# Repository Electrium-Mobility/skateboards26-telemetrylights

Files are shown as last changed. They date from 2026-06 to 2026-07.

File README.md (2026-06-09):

# Design

This is a mixed telemetry + lights board. We will use sensors (accelerometer) to gather information, a STM to process the info, and lights/display to display the result. Depending on the acceleration of the skateboard, the lights change to a different color. Data will also be displayed on a LCD/OLED screen.

Items displayed are:

* Acceleration
* Current/voltage draw of our board
* Precharge current sense
  * For the last two points, assume a separate power distribution board will be connected, and will be providing those signals through connectors.

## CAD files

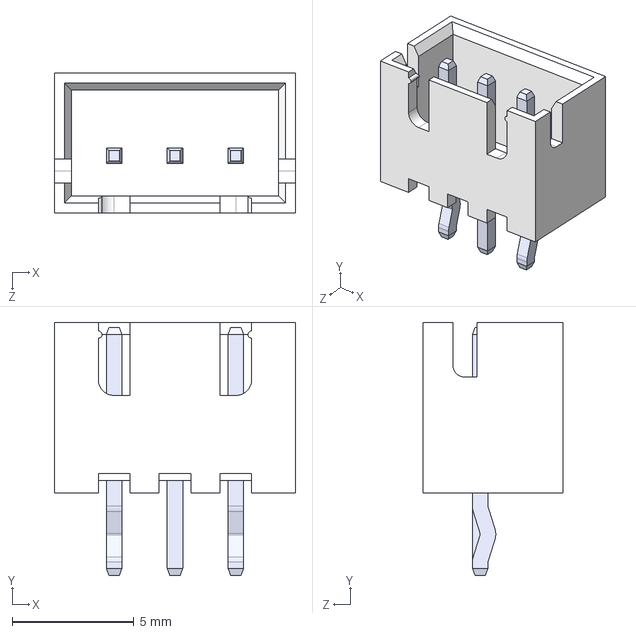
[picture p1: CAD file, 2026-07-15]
skateboard-3d-models/B3B-XH-A.STEP
9.90 x 10.4 x 5.75 mm

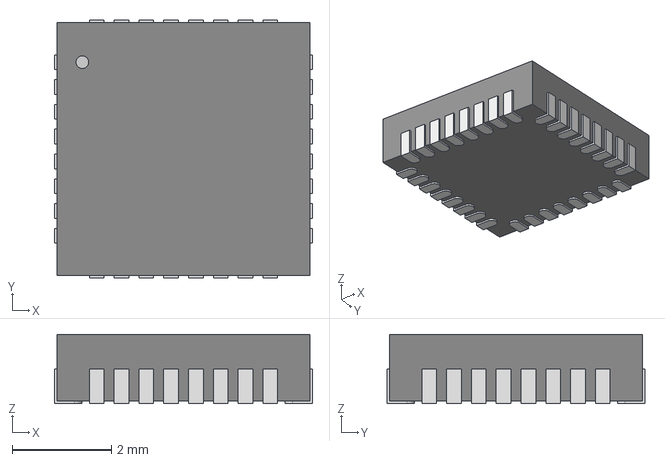
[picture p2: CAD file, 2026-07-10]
skateboard-3d-models/UFQFPN-32.step
5.20 x 5.20 x 1.40 mm

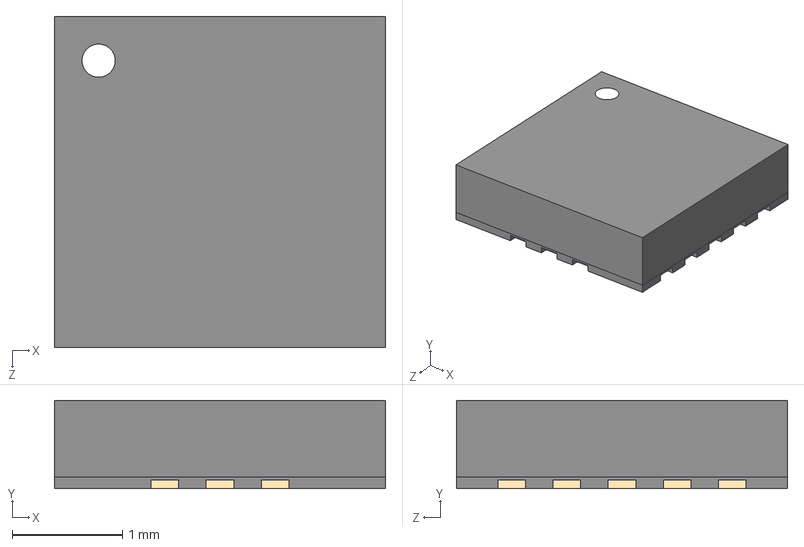
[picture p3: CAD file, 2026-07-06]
skateboard-3d-models/IAM-20381HT.step
3.00 x 0.8 x 3.00 mm

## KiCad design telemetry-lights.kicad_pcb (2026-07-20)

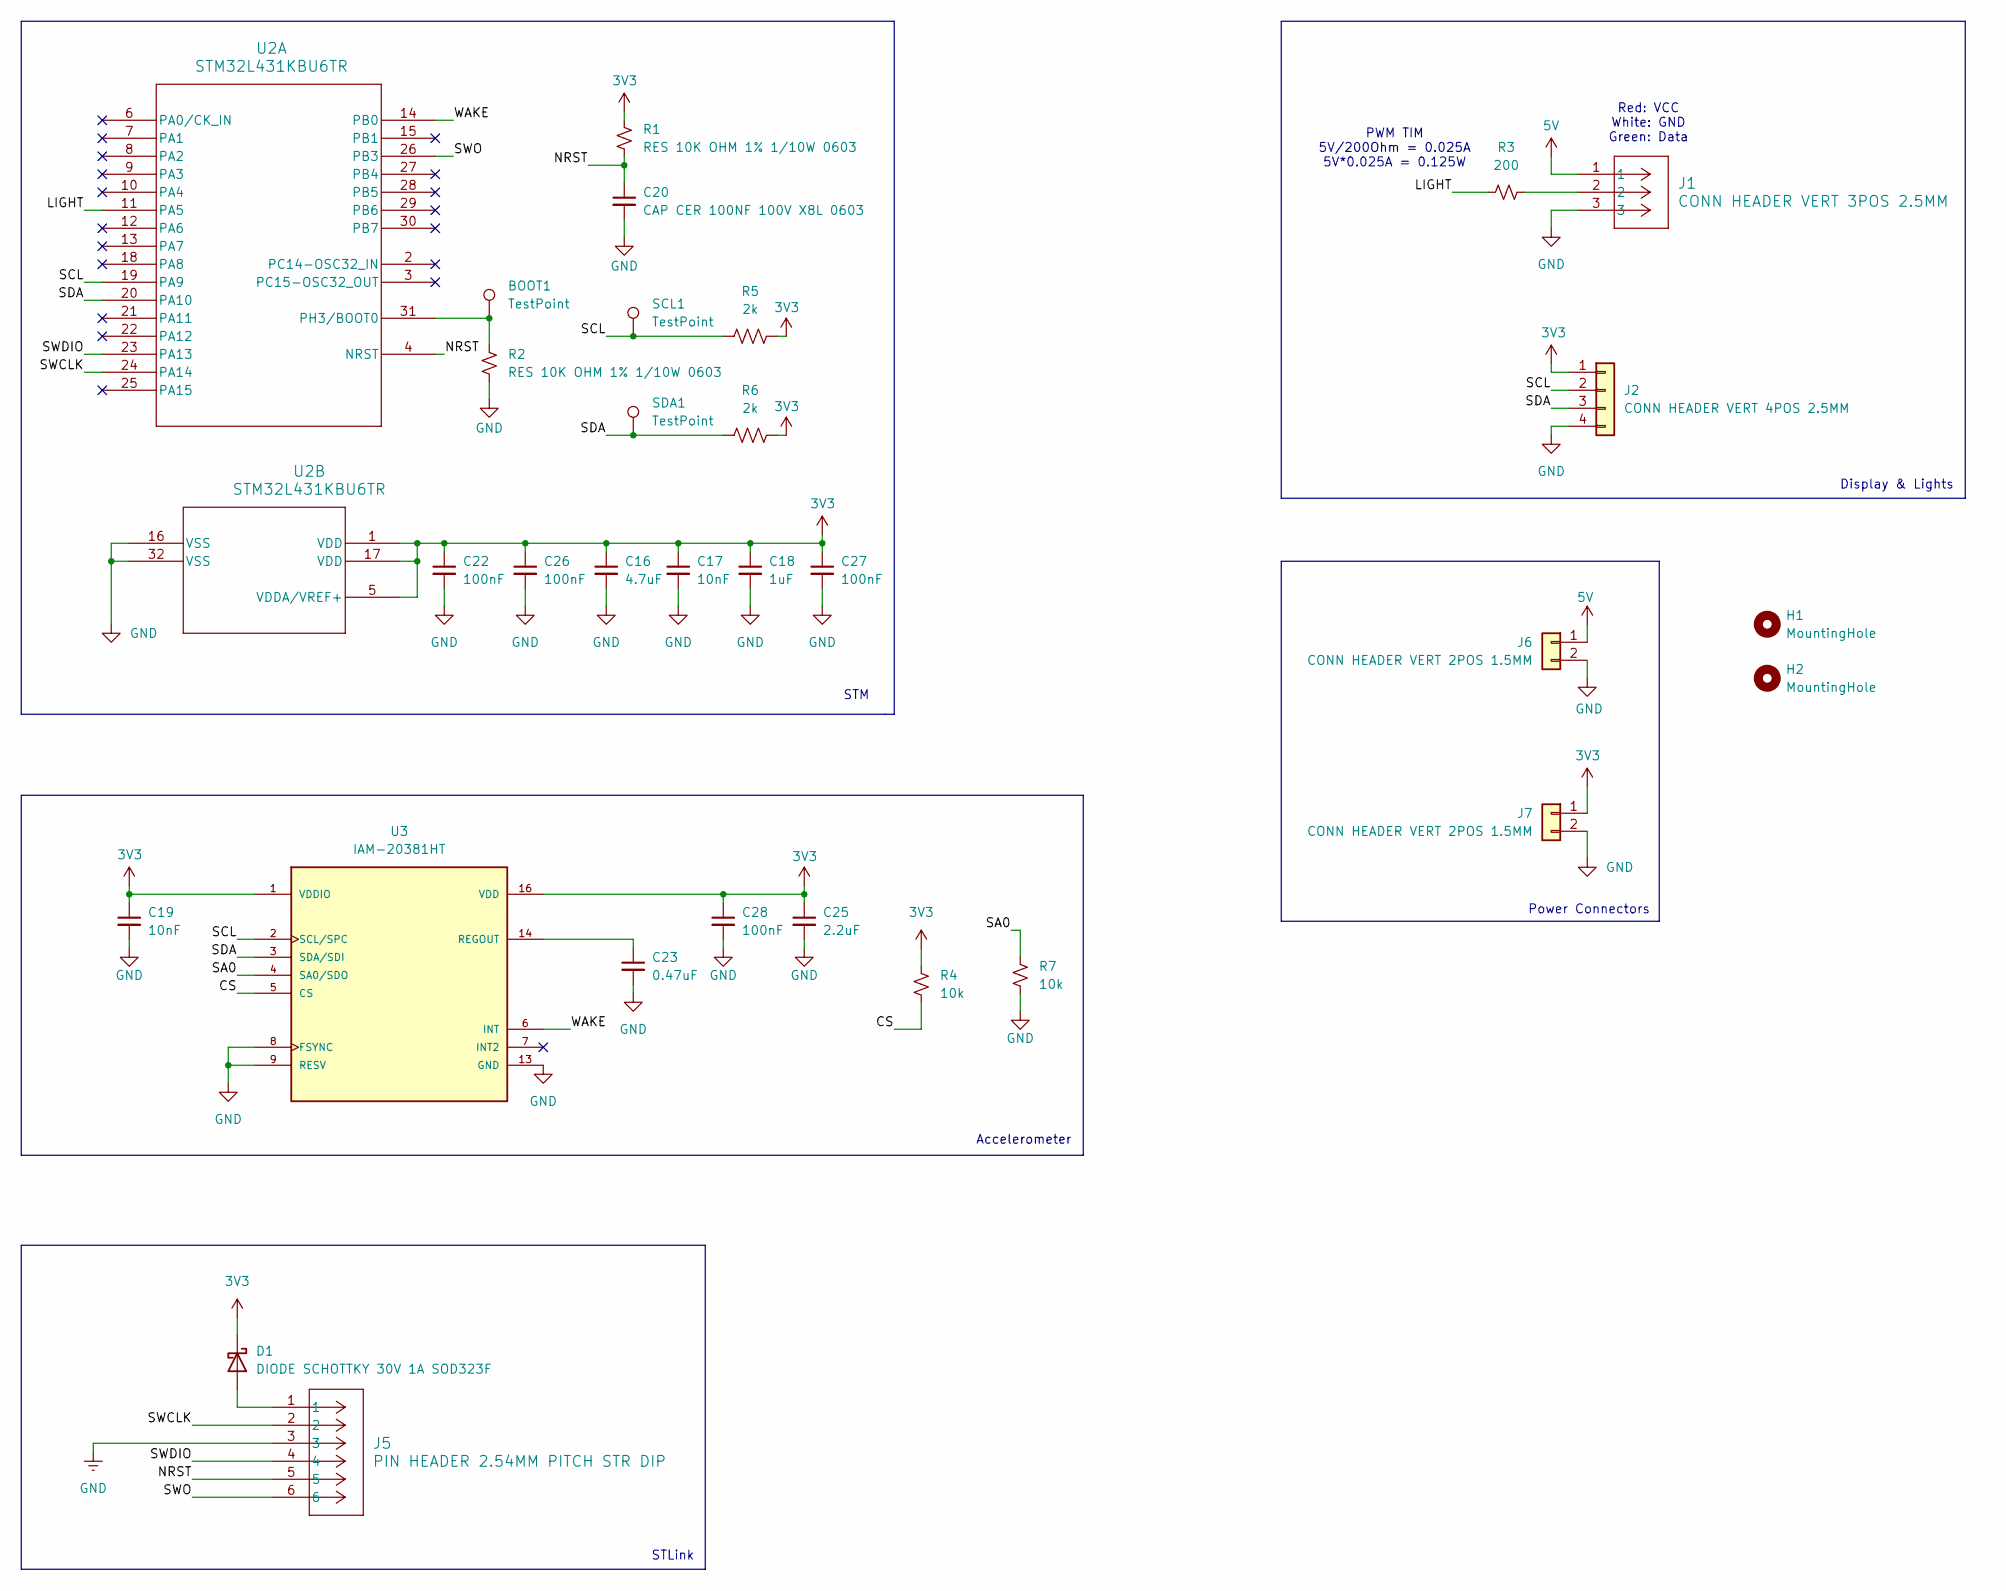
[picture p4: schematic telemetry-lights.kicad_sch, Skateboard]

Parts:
BOOT1: TestPoint; TestPoint_Pad_D1.0mm
C16: 4.7uF; C_0603_1608Metric
C17, C19: 10nF; C_0603_1608Metric
C18: 1uF; C_0603_1608Metric
C20: CAP CER 100NF 100V X8L 0603; C_0603_1608Metric
C22, C26, C27, C28: 100nF; C_0603_1608Metric
C23: 0.47uF; C_0603_1608Metric
C25: 2.2uF; C_0603_1608Metric
D1: DIODE SCHOTTKY 30V 1A SOD323F; P39_SOD-323P
H1, H2: MountingHole; MountingHole_2.5mm
J1: CONN HEADER VERT 3POS 2.5MM; CONN_B3B-XH-A_JST
J2: CONN HEADER VERT 4POS 2.5MM; JST_EH_B4B-EH-A_1x04_P2.50mm_Vertical
J5: PIN HEADER 2.54MM PITCH STR DIP; CONN6x1_G800W302018EU_AMP
J6, J7: CONN HEADER VERT 2POS 1.5MM; JST_ZH_B2B-ZR_1x02_P1.50mm_Vertical
R1, R2: RES 10K OHM 1% 1/10W 0603; R_0603_1608Metric
R3: 200; R_0603_1608Metric
R4, R7: 10k; R_0603_1608Metric
R5, R6: 2k; R_0603_1608Metric_Pad0.98x0.95mm_HandSolder
SCL1: TestPoint; TestPoint_Pad_D1.0mm
SDA1: TestPoint; TestPoint_Pad_D1.0mm
U2: STM32L431KBU6TR; UFQFPN-32
U3: IAM-20381HT; XDCR_IAM-20381HT; PARTREV 1.0

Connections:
3V3: C16.1, C17.1, C18.1, C19.1, C22.1, C25.1, C26.1, C27.1, C28.1, D1.1 (K), J2.1, J7.1, R1.1, R4.1, R5.2, R6.2, U2.1 (VDD), U2.5 (VDDA/VREF+), U2.17 (VDD), U3.1 (VDDIO), U3.16 (VDD)
5V: J1.1, J6.1
/CS: R4.2, U3.5 (CS)
/LIGHT: R3.1, U2.11 (PA5)
/NRST: C20.1, J5.5, R1.2, U2.4 (NRST)
/SA0: R7.1, U3.4 (SA0/SDO)
/SCL: J2.2, R5.1, SCL1.1 (1_1), U2.19 (PA9), U3.2 (SCL/SPC)
/SDA: J2.3, R6.1, SDA1.1 (1_1), U2.20 (PA10), U3.3 (SDA/SDI)
/SWCLK: J5.2, U2.24 (PA14)
/SWDIO: J5.4, U2.23 (PA13)
/SWO: J5.6, U2.26 (PB3)
/WAKE: U2.14 (PB0), U3.6 (INT)
GND: C16.2, C17.2, C18.2, C19.2, C20.2, C22.2, C23.2, C25.2, C26.2, C27.2, C28.2, J1.3, J2.4, J5.3, J6.2, J7.2, R2.2, R7.2, U2.16 (VSS), U2.32 (VSS), U3.8 (FSYNC), U3.9 (RESV), U3.10 (RESV), U3.11 (RESV), U3.12 (RESV), U3.13 (GND), U3.15 (RESV)
unnamed: D1.2 (A), J5.1
unnamed: J1.2, R3.2
unnamed 15: BOOT1.1, R2.1, U2.31 (PH3/BOOT0); also elsewhere on the board
unnamed: C23.1, U3.14 (REGOUT)

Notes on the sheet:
Accelerometer
PWM TIM 5V/200Ohm = 0.025A 5V*0.025A = 0.125W
Red: VCC White: GND Green: Data
STM
Display & Lights
STLink
Power Connectors

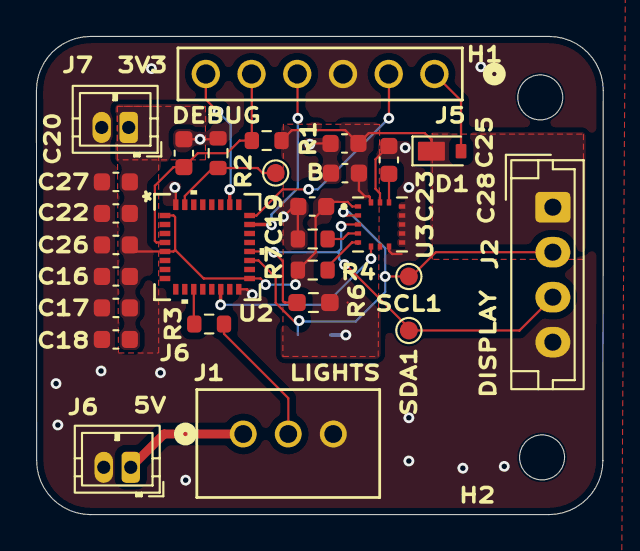
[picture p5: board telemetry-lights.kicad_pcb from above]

Board: 2 copper layers, 31.5 x 26.6 mm, 31 parts (1 on the bottom side), 17 nets.

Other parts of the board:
B: TestPoint; TestPoint_Pad_D1.0mm

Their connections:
unnamed 15: B.1 (1_1); also elsewhere on the board

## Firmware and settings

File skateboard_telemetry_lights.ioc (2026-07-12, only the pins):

Mcu.UserName=STM32L431KBUx
PA0.Signal=GPIO_Output
PA10.Signal=I2C1_SDA
PA11.Signal=CAN1_RX
PA12.Signal=CAN1_TX
PA9.Signal=I2C1_SCL
PB1.Signal=GPIO_Output
PB6.Signal=GPIO_Output

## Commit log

2026-06-14 Initialize KiCad project with empty custom symbol and footprint libraries
    [telemetry-lights.kicad_pcb, telemetry-lights.kicad_sch]
2026-07-06 initial schematic draft
    [IAM-20381HT.step, telemetry-lights.kicad_sch]
2026-07-08 Add all pull-up resistors and interrupt pins
    [telemetry-lights.kicad_sch]
2026-07-08 update schematic label
    [telemetry-lights.kicad_sch]
2026-07-08 added footprints
    [telemetry-lights.kicad_sch]
2026-07-08 Updated input connectors and fixed ground and source orientation
    [telemetry-lights.kicad_sch]
2026-07-10 Rearranged pins for accelorometer to match datasheet
    [telemetry-lights.kicad_sch]
2026-07-10 Created symbol and footprint libraries, accelorometer added
    [IAM-20381HT.step, telemetry-lights.kicad_sch]
2026-07-10 Updated libraries: accelorometer added
    [telemetry-lights.kicad_sch]
2026-07-10 Added STM chip to all libraries + CAD, fixed up accelorometer in schematic (still not done)
    [UFQFPN-32.step, telemetry-lights.kicad_sch]
2026-07-11 Add test points and replace pull-up resistors
    [telemetry-lights.kicad_sch]
2026-07-11 Label interrupt pins and add no connect flags
    [telemetry-lights.kicad_sch]
2026-07-12 altered schematic
    [telemetry-lights.kicad_sch]
2026-07-12 reorganized schematic
    [telemetry-lights.kicad_sch]
2026-07-13 changed footprints
    [telemetry-lights.kicad_sch]
2026-07-14 Move interrupt from PB1 to PA1
    [telemetry-lights.kicad_sch]
2026-07-15 revised schematic
    [B3B-XH-A.STEP, telemetry-lights.kicad_sch]
2026-07-15 minor revisions
    [telemetry-lights.kicad_sch]
2026-07-18 Change pin connected to lights
    [telemetry-lights.kicad_sch]
2026-07-18 Rough Layout Started for Accelerometer
    [telemetry-lights.kicad_pcb, telemetry-lights.kicad_sch]
2026-07-18 Component Placement Complete - To be Verified and Traced
    [telemetry-lights.kicad_pcb]
2026-07-18 started tracing
    [telemetry-lights.kicad_pcb]
2026-07-19 Add connections and copper fill
    [telemetry-lights.kicad_pcb, telemetry-lights.kicad_sch]
2026-07-20 Update trace thickness and fill zones
    [telemetry-lights.kicad_pcb]
2026-07-20 updated layout
    [telemetry-lights.kicad_pcb]
2026-07-20 final layout changes
    [telemetry-lights.kicad_pcb, telemetry-lights.kicad_sch]
